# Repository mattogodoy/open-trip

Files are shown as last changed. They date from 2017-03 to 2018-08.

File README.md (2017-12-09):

# open-trip

Open Trip is an Open Source **Arduino** project for an all-in-one rally roadbook.

For a complete and useful roadbook setup, you usually need a motor controlled box for the paper roll and two displays so you can see the partial trip in one, and the total trip in the other, or the partial trip in one and the heading degrees in the other. Also, you need 3 buttons to control the displays, and a "joystick" to control the paper roll.

Since the off-the-shelf solutions like the [ICO Rallye](http://www.icoracing.com/collections/ico-racing-products/products/rallye-max-g) for the displays (you need two) and the [MD Roadbook Reader](http://www.rallymanagementservices.com/products/md-roadbook-reader) are quite expensive, I'm making my own setup and sharing everything I learn in the process with you.

My goal is to emulate the most important features of the ICO Rallye so you won't miss anything.

# DETAILS

A more detailed guide is available at [my blog](https://matto.io/roadbook-con-tripmaster/). It is written in spanish, but you'll understand what's important.

### Hardware
* Two configurable backlit LCD displays
* Magnetometer to measure heading
* Hall effect sensor to measure distance and speed
* Motor to rotate the paper roll
* LED strip to retro-illuminate the paper roll
* Buttons to increase / decrease / reset distance
* Temporary bidirectional switch to control the roadbook motor
* Arduino Nano as the processing unit

### Features
* Menu to configure settings
* Configurable screens to display
	* Partial distance (in kilometers)
	* Total distance (in kilometers)
	* Compass (in degrees)
	* Speed (in kilometers / hour)
* Configurable wheel circumference (in milimeters)
* Configurable backlight (enabled / disabled)
* Automatic calibration option
* Configurable Magnetic Declination (http://www.magnetic-declination.com/)
* Configurable distance measures (Kilometers or Miles)
* All configuration parameters are persisted in EEPROM memory

### Setup

* Install Arduino libraries [to-do]

# Notes

### Wheel circumference and lying odometer

It's a well known fact that cars and motorcycle's speedometers lie. They always read higher than the real value (http://gpssystems.net/accurate-gpsbased-speedometer/).
The reasons for that are beyond this project, but I'm using my GPS to measure distances and try to imitate the results in the *open-trip* odometer.

I measured the wheel in my bike and I got 2007 milimeters. It turns out that I'm getting wrong reads, so after some calculation, I ended up using 2045 milimeters and this gives me the exact same distance number as the GPS, so I'll stick to that value. The bike's own odometer always shows more.

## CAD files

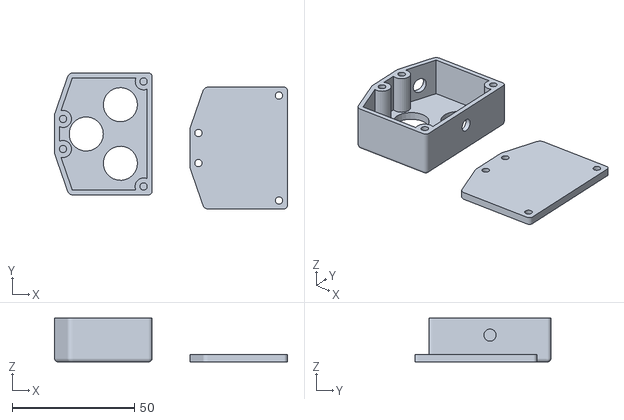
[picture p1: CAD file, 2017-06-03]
3d_models/Mando_fixed.stl
95.5 x 55.8 x 18.0

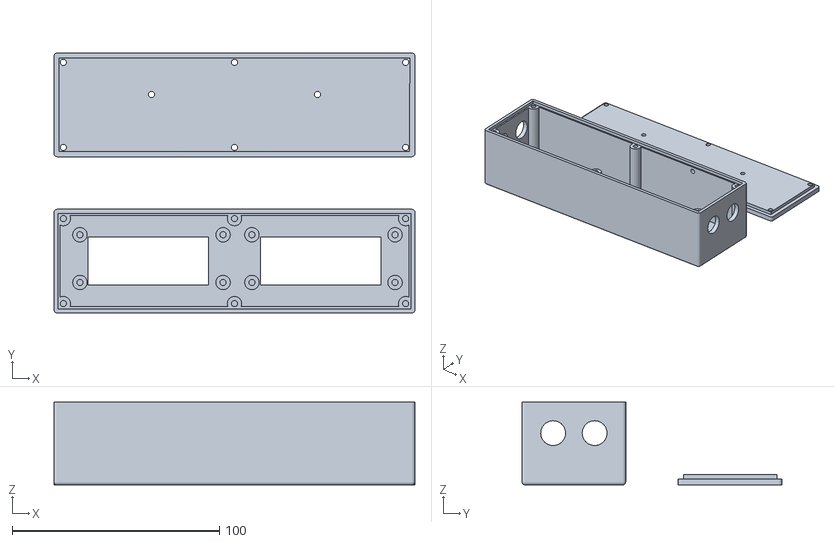
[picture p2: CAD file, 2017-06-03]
3d_models/TripMaster_small.stl
174.0 x 125.3 x 40.0

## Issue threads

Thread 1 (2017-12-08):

additionnal counter?

Lepterois, 2017-12-08:
Hi! great project!
I'm going to make one for my bike!
Do you think, is it possible to add an rpm counter for the engine?
Thanks to reply!

mattogodoy, 2017-12-09:
Hi!
Sure, it is possible, but for that you should have a way to measure every revolution. Most people makes it using the spark plug as a way to count. For instance: https://kokoraskostas.blogspot.com.es/2013/12/arduino-inductive-spark-plug-sensor.html

Good luck!

Lepterois, 2017-12-11:
Thanks for the reply!
Is it possible to use the original wires of the rpm meter?

mattogodoy, 2017-12-11:
Well, that might be possible but I am not sure how to do it. Maybe every bike brand has a different signal for that, or is it universal?
Sorry, I don't know :)

Lepterois, 2017-12-12:
I don't know at all. I'm completly newbie ;-)

Closed 2018-10-01.

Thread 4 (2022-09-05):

Compensacion de inclinacion

Thomas6500, 2022-09-05:
Hola

comp solventaste la inclinacion del magnetometro para tener un rumbo correcto?
estoy implementando una brujula con rumbo para 4x4 , pero afecta la inclinación del vehículo.
gracias

mattogodoy, 2022-09-06:
Buenas!
No he compensado inclinación, pero sí lo he hecho con la declinación magnética.
Aquí puedes ver la parte del código que controla la brújula: https://github.com/mattogodoy/open-trip/blob/master/open-trip.ino#L411-L442

Se me ocurre que para hacer eso podrías añadir un acelerómetro que siempre sepa donde es "hacia abajo" y en función de eso compensas. Saludos!

Closed 2022-09-06.

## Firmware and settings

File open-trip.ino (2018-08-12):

// Buttons includes
#include <Button.h>
#include <ButtonEventCallback.h>
#include <PushButton.h>
#include <Bounce2.h>

// Compass includes
#include <Wire.h>
#include <Adafruit_Sensor.h>
#include <Adafruit_HMC5883_U.h>

const int pin_sensor = 2;
const int pin_display_a_cs = 3;
const int pin_display_a_wr = 4;
const int pin_display_a_data = 5;
const int pin_display_b_cs = 6;
const int pin_display_b_wr = 7;
const int pin_display_b_data = 8;
const int pin_joystick_up = 9;
const int pin_joystick_down = 10;
const int pin_motor_output_a = 11;
const int pin_motor_output_b = 12;
const int pin_button_up = 15;
const int pin_button_center = 14;
const int pin_button_down = 16;
const int pin_light = 17;

// IMPORTANT: these are the indexes for menu[] array.
// If new options are added, update these values.
int maxMenuIndex = 6;
int minSubmenuIndex = 7; // Partial
int maxSubmenuIndex = 10; // Speed
int selectedMenuOption = 0;
int selectedSubMenuOption = minSubmenuIndex;
int btnHoldDelay = 1000;
int btnHoldRepeat = 30;

float previousTripTotal = 0;

unsigned long previousMillis = 0;
unsigned long previousMillisSpeed = 0;
unsigned long previousMillisDistance = 0;
const long displayRefreshInterval = 500;
const long autoSaveAfter = 3000;

bool inMenu = false;
bool inSubMenu = false;
bool lightsOn = false;
bool autoCalibrate = false;
bool distanceAlreadySaved = true;

// Interruption variables for wheel sensor
const byte interruptPin = pin_sensor;
volatile byte revs = 0;

// This is to convert float values to int and display them
long int displayValues[] = {
    0, // Partial
    0, // Total
    0, // Heading
    0  // Speed
};

struct Configuration {
  int version;
  int showInDisplay1;
  int showInDisplay2;
  int lightsOn;
  int autoCalibrate;
  int circumference;
  float declinationAngle;
  float trip_partial = 0;
  float trip_total = 0;
} config;

PushButton button_up = PushButton(pin_button_up);
PushButton button_center = PushButton(pin_button_center);
PushButton button_down = PushButton(pin_button_down);

// Assign a unique ID to this sensor at the same time
Adafruit_HMC5883_Unified mag = Adafruit_HMC5883_Unified(12345);

void setup() {
  Serial.begin(9600);
  
  loadConfig();

  pinMode(pin_display_a_cs, OUTPUT);
  pinMode(pin_display_a_wr, OUTPUT);
  pinMode(pin_display_a_data, OUTPUT);
  pinMode(pin_display_b_cs, OUTPUT);
  pinMode(pin_display_b_wr, OUTPUT);
  pinMode(pin_display_b_data, OUTPUT);

  pinMode(interruptPin, INPUT_PULLUP);
  attachInterrupt(digitalPinToInterrupt(interruptPin), revsCount, FALLING);

  // Init displays
  Init_1621(0);
  Init_1621(1);

  button_up.onPress(onButtonUpPressed);
  button_up.onHoldRepeat(btnHoldDelay, btnHoldRepeat, onButtonUpPressed);

  button_center.onRelease(onButtonCenterReleased);
  button_center.onHold(btnHoldDelay, onButtonCenterHold);

  button_down.onPress(onButtonDownPressed);
  button_down.onHoldRepeat(btnHoldDelay, btnHoldRepeat, onButtonDownPressed);

  // Initialise the compass
  if(!mag.begin()) {
    Serial.println(F("Ooops, no HMC5883 detected... Check your wiring!"));
  }

  revs = 0;

  updateScreens();
}

void loop() {
  button_up.update();
  button_center.update();
  button_down.update();
  sensorUpdate();
  calculateHeading();
  calculateSpeed();
  autoSave();
}

// Interrupt Service Routine (ISR)
void revsCount() {
  revs++;
}

void sensorUpdate() {

  byte revsTmp = revs;

  if(revsTmp > 0)
  {
    // This will count as many revolutions as added by 
    // the interruptions and reset them for the next loop
    config.trip_partial += (config.circumference / 100000.0) * revsTmp; // Count 1 every 100 meters
    config.trip_total += (config.circumference / 100000.0) * revsTmp; // Count 1 every 100 meters

      
    revs -= revsTmp;  

    distanceAlreadySaved = false;
    previousMillisDistance = millis(); // Renew time for auto-save
    
    Serial.println(F("SENSOR detected"));
    displayValues[0] = config.trip_partial;
    displayValues[1] = config.trip_total;
    Serial.print("trip_partial: ");
    Serial.println(config.trip_partial, 6);
    
    updateScreens();
  }

}

void loadConfig() {
  Serial.println(F("---> Loading saved data..."));

  EEPROM_read(0, config);

  Serial.println(config.version);
  Serial.println(config.showInDisplay1);
  Serial.println(config.showInDisplay2);
  Serial.println(config.lightsOn);
  Serial.println(config.autoCalibrate);
  Serial.println(config.circumference);
  Serial.println(config.declinationAngle, 6);
  Serial.println(config.trip_partial);
  Serial.println(config.trip_total);

  if(config.version != 123){
    Serial.println(F("---> No configuration data found. Setting up default values..."));
    
    config.showInDisplay1 = 0; // Partial distance
    config.showInDisplay2 = 3; // Speed
    config.lightsOn = 0;
    config.autoCalibrate = 0;
    config.circumference = 2040; // KTM 1190 Adventure with Conti Trail Attack
    config.declinationAngle = 0.01425352f; // Madrid
    config.version = 123;
    config.trip_partial = 0;
    config.trip_total = 0;

    saveConfig();
  } else {
    displayValues[0] = config.trip_partial;
    displayValues[1] = config.trip_total;
  }

  Serial.println(F("---> DONE"));
}

void saveConfig(){
  EEPROM_write(0, config);
  Serial.println(F("---> CONFIG SAVED!"));

  Serial.println(config.version);
  Serial.println(config.showInDisplay1);
  Serial.println(config.showInDisplay2);
  Serial.println(config.lightsOn);
  Serial.println(config.autoCalibrate);
  Serial.println(config.circumference);
  Serial.println(config.declinationAngle, 6);
  Serial.println(config.trip_partial);
  Serial.println(config.trip_total);
}

void onButtonUpPressed(Button& btn){
  Serial.println(F("button UP pressed"));

  if(inMenu){

    if(selectedMenuOption > 0){
      HT1621_all_off(16, 0);
      selectedMenuOption--;
    }

    switch(selectedMenuOption){
      case 0:
      case 1:
        minSubmenuIndex = 7;
        maxSubmenuIndex = 10;
        break;
      case 4:
      case 5:
        minSubmenuIndex = 11;
        maxSubmenuIndex = 12;
        break;
      case 6:
        minSubmenuIndex = 13;
        maxSubmenuIndex = 14;
        break;
    }

    selectedSubMenuOption = minSubmenuIndex;
  } else if(inSubMenu){
    if(selectedMenuOption == 2){
      config.circumference++;

      if(config.circumference > 9999){
        config.circumference = 9999;
      }
    } else {
      if(selectedSubMenuOption > minSubmenuIndex){ 
        HT1621_all_off(16, 1);
        selectedSubMenuOption--;
      }
    }
  } else {
    config.trip_partial += 1;
    config.trip_total += 1;
    displayValues[0] = config.trip_partial;
    displayValues[1] = config.trip_total;
  }

  updateScreens();
}

void onButtonCenterReleased(Button& btn, int duration){
  // This avoids calling this callback when releasing
  // the center button after a Hold event
  if(duration >= btnHoldDelay)
    return;

  Serial.println(F("button CENTER pressed"));
  if(inMenu){
    switch(selectedMenuOption){
      case 0:
        selectedSubMenuOption = maxMenuIndex + config.showInDisplay1 + 1;
        break;
      case 1:
        selectedSubMenuOption = maxMenuIndex + config.showInDisplay2 + 1;
        break;
      case 4:
        selectedSubMenuOption = 12 - config.lightsOn; // 12 is the number of the position of the ON / OFF in menu
        break;
      case 5:
        selectedSubMenuOption = 12 - config.autoCalibrate; // 12 is the number of the position of the ON / OFF in menu
        break;
      case 6:
        selectedSubMenuOption = 14;
        break;
    }

    inMenu = false;
    inSubMenu = true;
    Serial.println(F("State changed: inSubMenu"));
  } else if(inSubMenu){
    switch(selectedMenuOption){
      case 0:
        config.showInDisplay1 = selectedSubMenuOption - minSubmenuIndex;
        saveConfig();
        inSubMenu = false;
        break;
      case 1:
        config.showInDisplay2 = selectedSubMenuOption - minSubmenuIndex;
        saveConfig();
        inSubMenu = false;
        break;
      case 2:
        saveConfig();
        inSubMenu = false;
        break;
      case 6:
        if(selectedSubMenuOption == 13){
          resetConfig();
          inSubMenu = false;
        }
        break;
    }
  } else {
    config.trip_partial = 0;
    displayValues[0] = config.trip_partial;
  }
  updateScreens();
}

void onButtonCenterHold(Button& btn){
  Serial.println(F("button CENTER hold"));

  if(inMenu){
    inMenu = false;
    inSubMenu = false;
    Serial.println(F("State changed: none"));
  } else if(inSubMenu){
    inSubMenu = false;
    inMenu = true;
    Serial.println(F("State changed: inMenu"));
  } else {
    inMenu = true;
    Serial.println(F("State changed: inMenu"));
  }

  HT1621_all_off(6, 0);
  HT1621_all_off(6, 1);

  updateScreens();
}

void onButtonDownPressed(Button& btn){
  Serial.println(F("button DOWN pressed"));
  if(inMenu){
    if(selectedMenuOption < maxMenuIndex){
      HT1621_all_off(6, 0);
      selectedMenuOption++;
    }

    switch(selectedMenuOption){
      case 0:
      case 1:
        minSubmenuIndex = 7;
        maxSubmenuIndex = 10;
        break;
      case 4:
      case 5:
        minSubmenuIndex = 11;
        maxSubmenuIndex = 12;
        break;
      case 6:
        minSubmenuIndex = 13;
        maxSubmenuIndex = 14;
        break;
    }

    selectedSubMenuOption = minSubmenuIndex;
  } else if(inSubMenu){
    if(selectedMenuOption == 2){
      config.circumference--;

      if(config.circumference < 0){
        config.circumference = 0;
      }
    } else {
      if(selectedSubMenuOption < maxSubmenuIndex){
        HT1621_all_off(16, 1);
        selectedSubMenuOption++;
      }
    }
  } else {
    config.trip_partial -= 1;
    config.trip_total -= 1;

    if(config.trip_partial < 0){
      config.trip_partial = 0;
    }

    if(config.trip_total < 0){
      config.trip_total = 0;
    }

    displayValues[0] = config.trip_partial;
    displayValues[1] = config.trip_total;
  }
  updateScreens();
}

void calculateHeading() {
  if(config.showInDisplay1 != 2 && config.showInDisplay2 != 2)
    return;

  unsigned long currentMillis = millis();

  // Get a new compass event
  sensors_event_t event; 
  mag.getEvent(&event);

  // Hold the module so that Z is pointing 'up' and you can measure the heading with x&y
  // Calculate heading when the magnetometer is level, then correct for signs of axis.
  float heading = atan2(event.magnetic.y, event.magnetic.x);

  // Once you have your heading, you must then add your 'Declination Angle', which is the 'Error' of the magnetic field in your location.
  // Find yours here: http://www.magnetic-declination.com/
  // Mine is: -13* 2' W, which is ~13 Degrees, or (which we need) 0.22 radians
  // If you cannot find your Declination, comment out these two lines, your compass will be slightly off.
  //float declinationAngle = 0.22;
  heading += config.declinationAngle;
  
  // Correct for when signs are reversed.
  if(heading < 0)
    heading += 2 * PI;

  // Check for wrap due to addition of declination.
  if(heading > 2 * PI)
    heading -= 2 * PI;

  // Update data and display
  if (currentMillis - previousMillis >= displayRefreshInterval) {
    previousMillis = currentMillis;

    // Convert radians to degrees for readability.
    float headingDegrees = heading * 180 / M_PI;
    displayValues[2] = headingDegrees;
 
    updateScreens();
  }
}

void autoSave(){
  if(distanceAlreadySaved == true){
    return;
  }

  unsigned long currentMillis = millis();

  if (currentMillis - previousMillisDistance >= autoSaveAfter) {
    Serial.println(F("Auto-saving distance..."));

    saveConfig();
    distanceAlreadySaved = true;
  }
}

void calculateSpeed(){
  unsigned long currentMillis = millis();

  // Update data and display
  if (currentMillis - previousMillisSpeed >= 1000) {
    previousMillisSpeed = currentMillis;

    float km = (config.trip_total - previousTripTotal) / 10;
    displayValues[3] = (km * 3600) + 0.5; // Adding 0.5 is the easiest way to round up (int to float trims)
    previousTripTotal = config.trip_total;
 
    updateScreens();
  }
}

void resetConfig(){
  config.version = 000;
  saveConfig();
  Serial.println(F("--> CONFIG CLEARED"));
  inMenu = false;
  inSubMenu = false;
}

void updateScreens() {
  if(inMenu){
    display_word(selectedMenuOption, 0);
    HT1621_all_off(6, 1);
  } else if(inSubMenu){
    display_word(selectedMenuOption, 0);

    switch(selectedMenuOption){
      case 0:
      case 1:
      case 4:
      case 5:
      case 6:
        display_word(selectedSubMenuOption, 1);
        break;
      case 2:
        display_number(config.circumference, 0, 0, 0, 1);
        break;
      case 3:
        display_number(config.declinationAngle, 0, 0, 0, 1);
        break;
    }
  } else {
    // Display 1
    switch(config.showInDisplay1){
      case 0:
        display_number(displayValues[0], 1, 1, 0, 0);
        break;
      case 1:
        display_number(displayValues[1], 1, 0, 1, 0);
        break;
      case 2:
        display_degrees(displayValues[2], 0, 0, 0, 0);
        break;
      case 3:
        display_number(displayValues[3], 0, 1, 1, 0);
        break;
    }

    // Display 2
    switch(config.showInDisplay2){
      case 0:
        display_number(displayValues[0], 1, 1, 0, 1);
        break;
      case 1:
        display_number(displayValues[1], 1, 0, 1, 1);
        break;
      case 2:
        display_degrees(displayValues[2], 0, 0, 0, 1);
        break;
      case 3:
        display_number(displayValues[3], 0, 1, 1, 1);
        break;
    }
  }
}

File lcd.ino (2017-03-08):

//Author: cantone-electonics
//More information welcome to : http://www.canton-electronics.com 
//Arduino 1.0.4
//Arduino uno R3
//5 DIGIT 7SEG LCD

/*---Segment Display Screen----
--5--
1---6
--2--
3---7
--4--
8 decimal point
----------------------*/

#define sbi(x, y)  (x |= (1 << y))   /*set Register x of y*/
#define cbi(x, y)  (x &= ~(1 << y))  /*Clear Register x of y*/
#define uchar unsigned char
#define uint  unsigned int
//Defined HT1621's command
#define  ComMode    0x52  //4COM,1/3bias  1000    010 1001  0
#define  RCosc      0x30  //on-chip RC oscillator(Power-on default)1000 0011 0000
#define  LCD_on     0x06  //Turn on LCD
#define  LCD_off    0x04  //Turn off LCD
#define  Sys_en     0x02  //Turn on system oscillator 1000   0000 0010
#define  CTRl_cmd   0x80  //Write control cmd
#define  Data_cmd   0xa0  //Write data cmd

// =======================
// ====== SCREEN A =======
// =======================
//Define port     HT1621 data port
#define pin_display_a_cs   pin_display_a_cs  //Pin 3 as chip selection output
#define pin_display_a_wr   pin_display_a_wr  //Pin 4 as read clock  output
#define pin_display_a_data pin_display_a_data  //Pin 5 as Serial data output

// =======================
// ====== SCREEN b =======
// =======================
//Define port     HT1621 data port
#define pin_display_b_cs   pin_display_b_cs  //Pin 6 as chip selection output
#define pin_display_b_wr   pin_display_b_wr  //Pin 7 as read clock  output
#define pin_display_b_data pin_display_b_data  //Pin 8 as Serial data output


/*0,1,2,3,4,5,6,7,8,9,A,b,C,c,d,E,F,*/    
const char num[] = {0xEB, 0x60, 0xC7, 0xE5, 0x6C, 0xAD, 0xAF, 0xE0, 0xEF, 0xED, 0xEE, 0x2F, 0x8B, 0x07, 0x67, 0x8F, 0x8E};
char dispnum[5] = {0x00, 0x00, 0x00, 0x00, 0x00};

/*
 *       a
 *       -
 *    e | | b
 *       -  <-f
 *    g | | c
 *       - . <-d
 *       h
 *       
 *   a b c d e f g h
 *   1 1 1 1 1 1 1 1 (all on) == 0b11111111
 *   
 *
 */

char char_null = 0b00000000;
char char_0    = 0b11101011;
char char_1    = 0b01100000;
char char_2    = 0b11000111;
char char_3    = 0b11100101;
char char_4    = 0b01101100;
char char_5    = 0b10101101;
char char_6    = 0b10101111;
char char_7    = 0b11100000;
char char_8    = 0b11101111;
char char_9    = 0b11101101;
char char_a    = 0b11100111;
char char_aa   = 0b11101110; // A
char char_b    = 0b00101111;
char char_c    = 0b00000111;
char char_cc   = 0b10001011; // C
char char_d    = 0b01100111;
char char_e    = 0b11001111;
char char_ee   = 0b10001111; // E
char char_f    = 0b10001110;
char char_g    = 0b11101101;
char char_h    = 0b00101110;
char char_hh   = 0b01101110; // H
char char_i    = 0b00100000;
char char_ii   = 0b01100000; // I
char char_j    = 0b01100011;
char char_jj   = 0b11100011; // J
char char_l    = 0b00001010;
char char_ll   = 0b00001011; // L
char char_n    = 0b00100110;
char char_nn   = 0b10100110; // ñ
char char_o    = 0b00100111;
char char_oo   = 0b11101011; // O
char char_p    = 0b11001110;
char char_q    = 0b11101100;
char char_r    = 0b00000110;
char char_s    = 0b10101101;
char char_t    = 0b00001111;
char char_u    = 0b00100011;
char char_uu   = 0b01101011; // U
char char_y    = 0b01101101;
char char_z    = 0b11000111;
char char_dot  = 0b00010000;
char char_less = 0b00000100; // -
char char_und  = 0b00000001; // _
char char_deg  = 0b11001100; // º

// Menus
char menu_display1[]      = { char_d, char_i, char_s, char_p, char_1, '\0' };
char menu_display2[]      = { char_d, char_i, char_s, char_p, char_2, '\0' };
char menu_circumference[] = { char_cc, char_ii, char_r, char_cc, char_null, '\0' };
char menu_declination[]   = { char_d, char_ee, char_cc, char_ll, char_null, '\0' };
char menu_light[]         = { char_ll, char_ii, char_g, char_hh, char_t, '\0' };
char menu_auto[]          = { char_aa, char_uu, char_t, char_oo, char_null, '\0' };
char menu_reset[]         = { char_r, char_ee, char_s, char_ee, char_t, '\0' };
char menu_partial[]       = { char_p, char_aa, char_r, char_t, char_null, '\0' };
char menu_total[]         = { char_t, char_oo, char_t, char_aa, char_ll, '\0' };
char menu_heading[]       = { char_hh, char_ee, char_aa, char_d, char_null, '\0' };
char menu_speed[]         = { char_s, char_p, char_ee, char_ee, char_d, '\0' };
char menu_on[]            = { char_oo, char_n, char_null, char_null, char_null, '\0' };
char menu_off[]           = { char_oo, char_f, char_f, char_null, char_null, '\0' };
char menu_yes[]           = { char_y, char_ee, char_s, char_null, char_null, '\0' };
char menu_no[]            = { char_n, char_oo, char_null, char_null, char_null, '\0' };

char* menu[] = {
  menu_display1,
  menu_display2,
  menu_circumference,
  menu_declination,
  menu_light,
  menu_auto,
  menu_reset,
  menu_partial,
  menu_total,
  menu_heading,
  menu_speed,
  menu_on,
  menu_off,
  menu_yes,
  menu_no
};


/**------------------------------------------------------------------------- 
                Name: SendBit_1621(send data) 
---------------------------------------------------------------------------*/ 

void SendBit_1621(uchar sdata, uchar cnt, int screen){ //High bit first
  uchar i;
  int DATA;
  int WR;
  
  switch(screen){
    case 0:
      DATA = pin_display_a_data;
      WR = pin_display_a_wr;
      break;
    case 1:
      DATA = pin_display_b_data;
      WR = pin_display_b_wr;
      break;
  }

  for(i = 0; i < cnt; i++){ 
    digitalWrite(WR, LOW);
    delayMicroseconds(20); 
    
    if(sdata & 0x80) 
      digitalWrite(DATA, HIGH); 
    else
      digitalWrite(DATA, LOW); 
  
    delayMicroseconds(20);
    digitalWrite(WR, HIGH);
    delayMicroseconds(20);
    sdata <<= 1; 
  } 

  delayMicroseconds(20);
}

/**------------------------------------------------------------------------- 
                  Name: SendCmd(send cmd) 
                  //Write MODE“100” AND 9 bits command 
---------------------------------------------------------------------------*/ 

void SendCmd_1621(uchar command, int screen){
  int CS;
  switch(screen){
    case 0:
      CS = pin_display_a_cs;
      break;
    case 1:
      CS = pin_display_b_cs;
      break;
  }

  digitalWrite(CS, LOW);
  SendBit_1621(0x80, 4, screen);
  SendBit_1621(command, 8, screen);
  digitalWrite(CS, HIGH);
}

/**------------------------------------------------------------------------- 
                Name: Write_1621send data and cmd) 
---------------------------------------------------------------------------*/ 

void Write_1621(uchar addr, uchar sdata, int screen){ 
  addr <<= 2;
  int CS;
  switch(screen){
    case 0:
      CS = pin_display_a_cs;
      break;
    case 1:
      CS = pin_display_b_cs;
      break;
  }

  digitalWrite(CS, LOW);
  SendBit_1621(0xa0, 3, screen);     //Write MODE“101”
  SendBit_1621(addr, 6, screen);     //Write addr high 6 bits
  SendBit_1621(sdata, 8, screen);    //Write data  8 bits
  digitalWrite(CS, HIGH);
}
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

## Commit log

2017-03-01 Added interrupt to ensure sensor pass-by detection.
2017-03-04 Added arrow show/hide functions. Corrected circumference.
    [lcd.ino, open-trip.ino]
2017-03-08 Unified templates inside a new file. Fixed speed calculation time. Fixed leading zero on speed. Corrected default circumference. Added some Notes in the README file
    [lcd.ino, open-trip.ino]
2017-03-09 Fixed default circumference. Fixed update rate for speed.
    [open-trip.ino]
2017-06-03 Added printable 3D models.
    [Mando_fixed.stl, TripMaster_small.stl]
